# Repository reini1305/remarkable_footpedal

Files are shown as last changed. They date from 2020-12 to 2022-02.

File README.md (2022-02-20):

# Remarkable 2 Foot Pedal

This repository contains schematics, a 3D model and code for a Teensy LC to connect a foot pedal switch to the pogo pins of a reMarkable 2.

## Pictures
Assembled and in action:

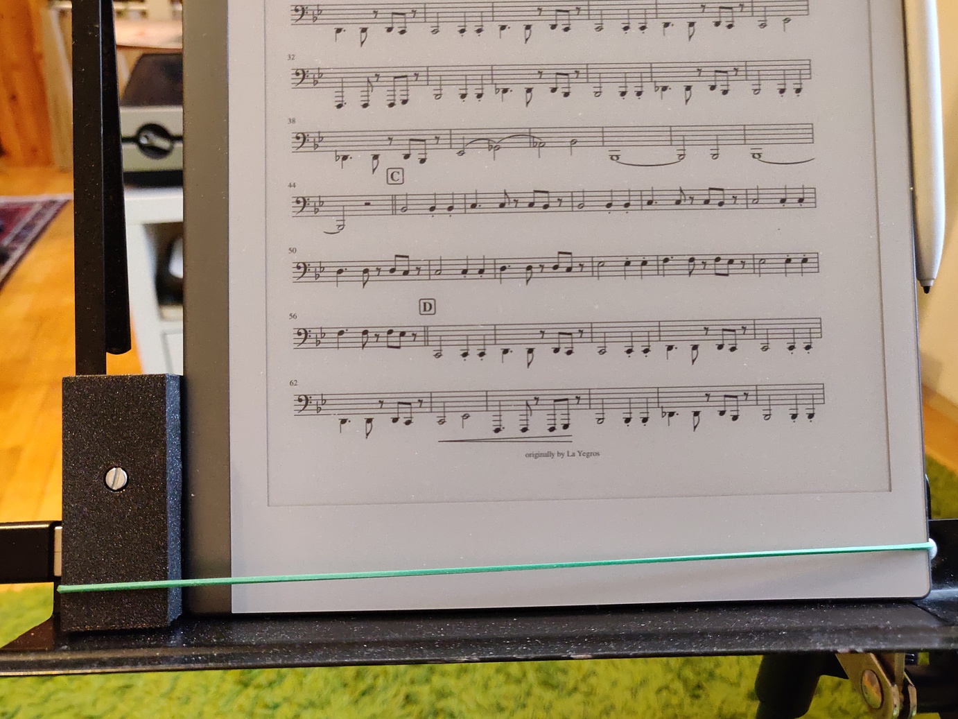
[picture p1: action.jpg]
Action

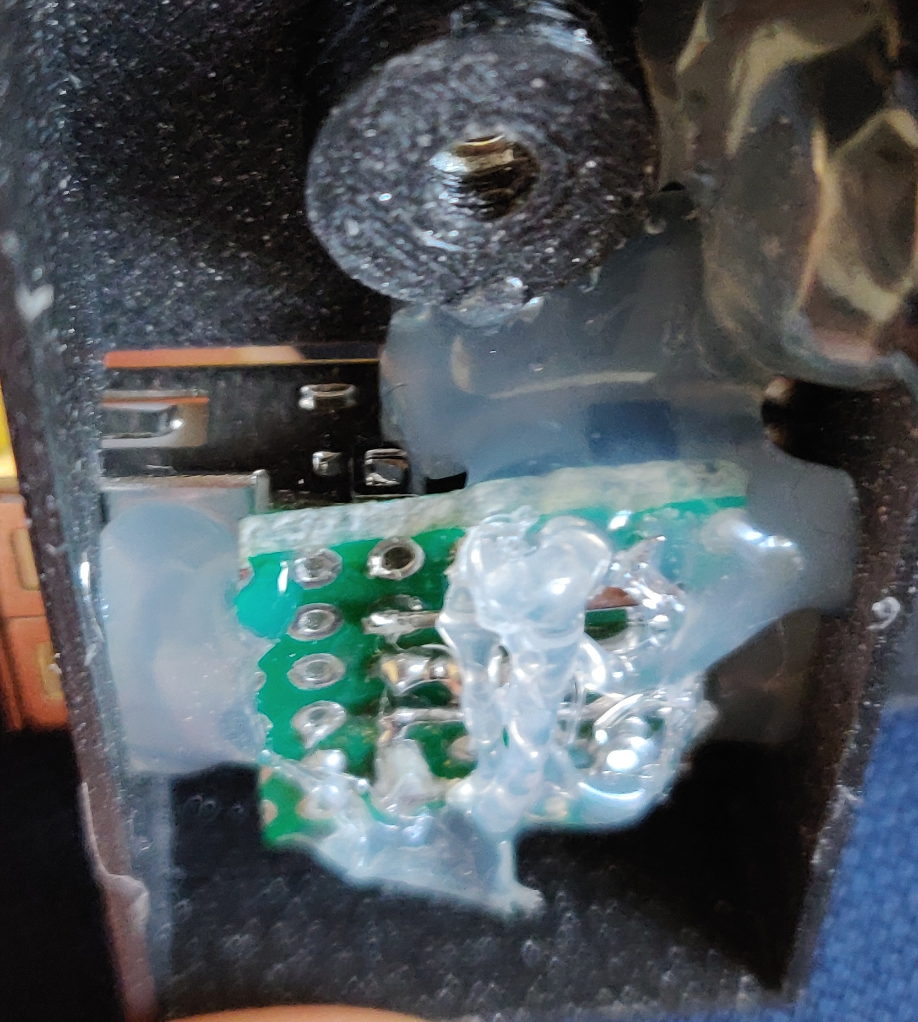
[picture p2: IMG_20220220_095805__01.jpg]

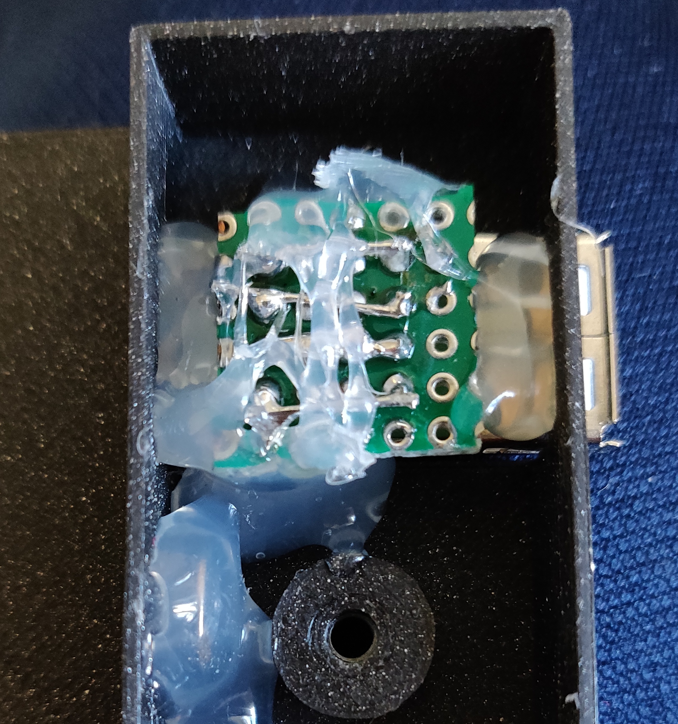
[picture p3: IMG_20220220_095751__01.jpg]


Pogo pin converter:

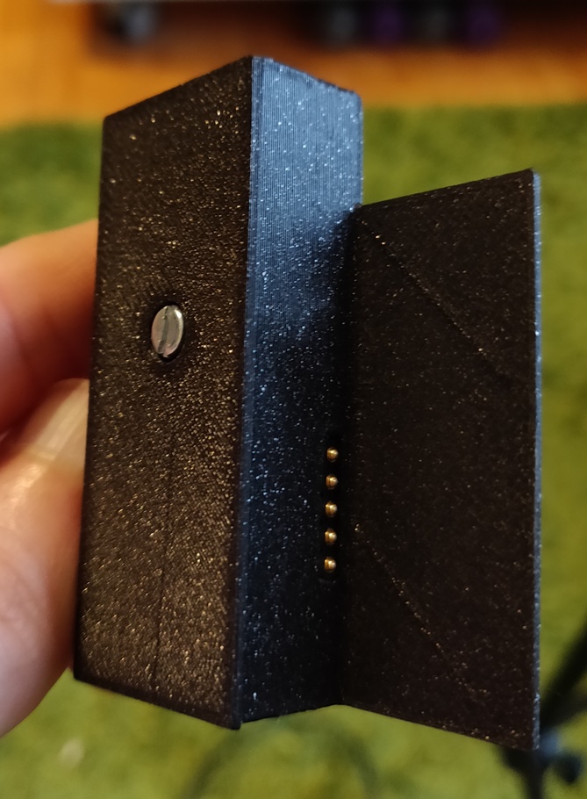
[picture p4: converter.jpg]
Pogo


Foot pedal:

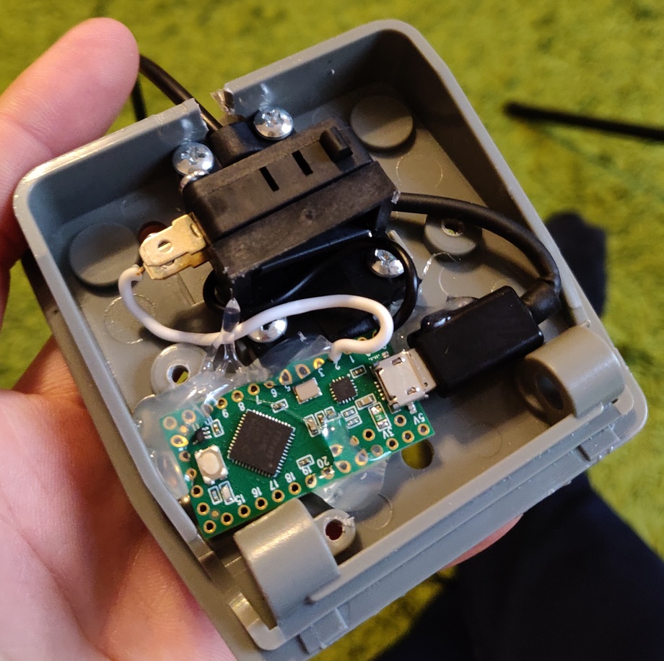
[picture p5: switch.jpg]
Foot pedal


## Necessary Hardware
- Teensy LC (or better) [here](https://www.pjrc.com/teensy/teensyLC.html)
- Foot pedal (e.g. [from Digikey](https://www.digikey.at/product-detail/de/adafruit-industries-llc/423/1528-1137-ND/5353597))
- USB-A connector (e.g. [from Digikey](https://www.digikey.at/product-detail/de/on-shore-technology-inc/USB-A1HSW6/ED2989-ND/2677750))
- Pogo pins (e.g. [from Digikey](https://www.digikey.at/product-detail/de/mill-max-manufacturing-corp/815-22-005-30-001101/ED1232-05-ND/3913218))
- Small neodym magnets to hold the adapter to the RM2

## Schematics
The pinout of the pogo pins is described in the [remarkable wiki](https://remarkablewiki.com/tech/rm2_otg_pogo):
~~~
(left to right, closest to USB-C)  
  
GND, ID, D+, D-, VBUS
~~~
Connecting GND to ID will enable the OTG power supply. If you mount the USB-port upside/down, you can simply connect the pins 1:1 as the USB pinout is:
~~~
(right to left)  
  
GND, D+, D-, VBUS
~~~

For the foot pedal, connect the switch to ground and a pin on the Teensy (the example code uses pin 2).

## Software
The sketch for the Teensy reads the input from pin 2. If it is pressed only once within 300ms, "Arrow Right" will be sent as keypress, it it is pressed twice, "Arrow Left" will be sent. This allows you to move forward and back through the document.

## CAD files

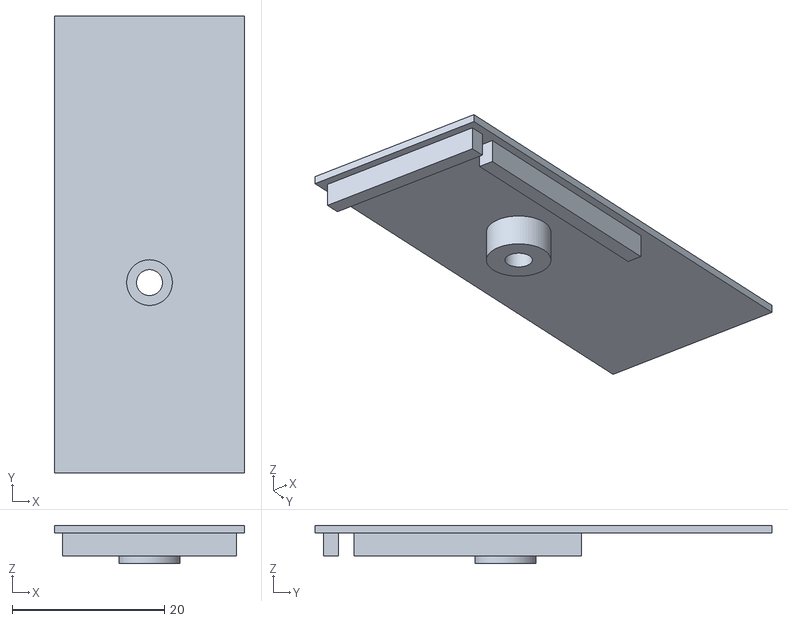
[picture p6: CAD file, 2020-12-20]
top.stl
25.0 x 60.0 x 5.00

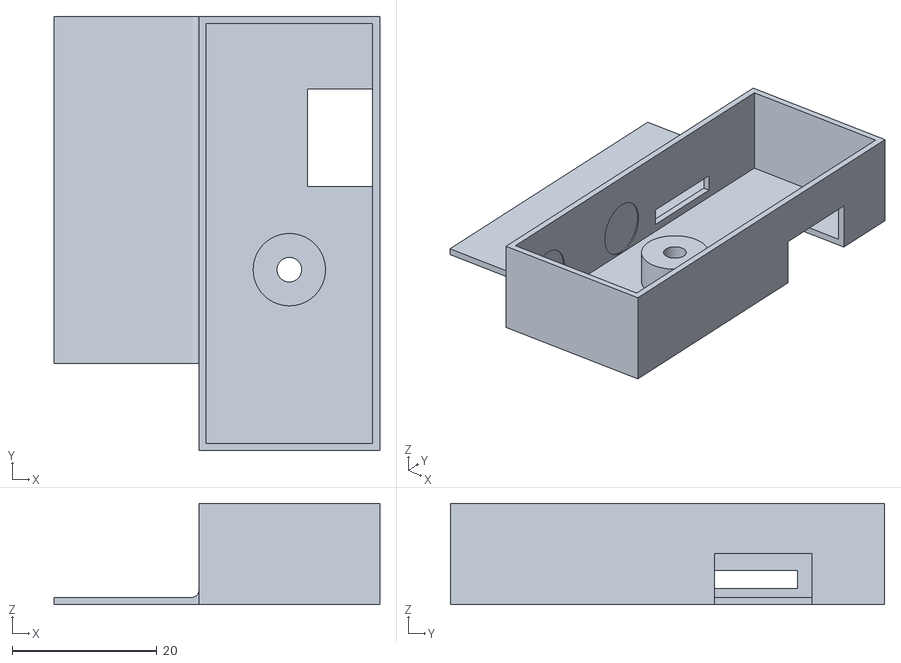
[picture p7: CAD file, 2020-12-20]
bottom.stl
45.0 x 60.0 x 14.0

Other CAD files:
box.FCStd

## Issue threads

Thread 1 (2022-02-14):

Help please!

Cwill95, 2022-02-14:
Hello, I would really like to create this product but am having some trouble!  First, the links in the message for the items needed are going to a web page in another country and in another language, and I’m having a hard time finding them exactly as linked in the US.  Would it be possible to refresh those links to a US based company?  Also not sure  what why’re correct, as the Pogo pins in the link look very different than the ones in the picture (picture shows 5 pins; link shows 4).  I’m also curious if you have some more pictures of the project that you can post with maybe some more detailed instructions?  It would be very much appreciated if possible!!

reini1305, 2022-02-14:
Hi! I've linked to Digikey since it is an international distributor. You might need to change the country in the settings, but you can definitely get everything in the US (with the part numbers). The pogo pins link shows 4 pins, but it is a 5 pin.
I'll open the adapter and try to take some more pictures, but please bear in mind that this is not intended to be a product but an afternoon hack of mine.

Cwill95, 2022-02-14:
Hi Christian, thanks for the quick response!  I think I've gotten the parts I need...  Not sure why your links take me to a german (looking?) page, but none the less, I've ordered the parts!  And I certainly understand what you mean...  I'm not looking to commercialize this either - just an "afternoon hack" for me too!  :-)

So, I'm looking through everything...  Never used Teensy, but I've used arduino before, so mildly familiar with the process here.  It looks like you have some 3d printer files, for printing the box that attaches to the side of the RM2, correct?  And the only thing inside that box is the pogo pins and the USB adapter?  I'm assuming that it will be rather self-intuitive how these pieces fit together inside the box, which is (presumably) two pieces held together by a screw?

The picture of the foot pedal looks like it has a cord coming out of it.  I also assume that somehow the cord to the footpedal is removed, and replaced by a USB cable that attached directly to the Teensy?  So the Teensy and the pogo box are both connected together by a male/male USB cable, is that correct?

Sorry to ask so much of you here, but this is EXACTLY what I've been looking for and I'm really excited to get it going!!

THanks,

Trey

reini1305, 2022-02-20:
Hi! I've attached two more images ofe the inside of the adapter. And yes, the two STL files are for the box to be 3d printed.
You're right that this box allows to plug in any USB device into the remarkable. I've remobed the foot switch cable and instead inserted a USB A to micro USB cable to connect to the Teensy. Instead of a teensy, one could also open up an old USB keyboard and xonnect the switch such that it produces a PgDown keypress to advance the page on the remarkable

Cwill95, 2022-03-14:
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

Hey!!  So I'm finally getting this thing put together and I'm a little confused out the pogo pins...  Did you just solder wires from the usb plug to the pins, and then hot glue everything to hold it in place?  The pic above is what I've got...  ordered everything directly from your links.  Your pic of the 3d printed box looks like it has some type of green board on it but can't tel what it is...  Did I maybe get a different part?

See pic - that's what I have

Cwill95, 2022-03-14:
And also, did you just "Hotwire" the Grn to ID pin?

reini1305, 2022-03-25:
Hi!
Sorry for the late answer. Yes, I've connected GND to ID as in the schematic. The green board is a "peg board" That I've cut to size (just to have something to mount the components to (similar to this https://www.neuhold-elektronik.at/catshop/popup_image.php?pID=7867). I've bent some connectors like those https://www.neuhold-elektronik.at/catshop/popup_image.php?pID=2688 90 degrees and soldered the pogo pins to them.

It should be possible to connect pogo pins and USB connector with wires though and fixing them into position with hot glue.

davidnixon, 2022-06-23:
This is such an awesome project. Thanks for posting! :raising_hand_man: I don't see the magnets in the pics. Can you add a pick of that? Maybe they are here?
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

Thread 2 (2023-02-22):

rm2 experience

cfenell, 2023-02-22:
Hi, a colleague has modified the CAD drawings and built an adapter for me, magnet mounting modified and positions adjusted to fit my rm2.  The magnets help finding the position but are too weak to make contact with the pogo pins, so an additional rubberband or piece of tape will be necessary.

I am  curious- what music viewer do you use in the photos, just the standard reMarkable application or something else?
Best regards, Fredrik

reini1305, 2023-03-07:
Hi! Awesome! I'm using the normal PDF viewer of Remarkable. I usually get sheet music as multi-page PDFs.

cfenell, 2023-04-03:
I'm still struggling to get a reliable connection to the pogo pins, are there any good tricks?
If I press the connector hard with one hand I can make a normal keyboard work in a text terminal for a short while, but the PDF reader does not seem to react.

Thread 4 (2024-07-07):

Using a Seeeduino Xiao SAMD21 instead of Teensy LC

chucktomasi, 2024-07-07:
Thanks for providing this repo. I've been inspired to try to build one myself based on your design. However, instead of the Teensy LC, I've opted to use the Seeeduino Xiao SAMD21 as it's much smaller. The software worked well (after a adding the Keyboard.h header). I can see that it is sending two different codes based on click/double-click.

Here's my issue... when I created the USB-A to pogo interface and tested it, the Xiao only powers on for about a second then goes dark. According to what I could find, it's only drawing 12mA. I believe that's almost half of what the Teensy LC takes. I'm not sure where I've gone wrong. It works fine on the "test bench" when connected to my laptop and Arduino IDE, but it's not powering properly from the RM2. Happy to provide any additional information if needed.

Any thoughts?

Thanks again

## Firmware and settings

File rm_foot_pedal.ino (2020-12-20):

// Detect the falling edge

// Include the Bounce2 library found here :
// https://github.com/thomasfredericks/Bounce-Arduino-Wiring
#include <Bounce2.h>

#define NEXT_KEY KEY_RIGHT_ARROW
#define PREV_KEY KEY_LEFT_ARROW
#define SWITCH_PIN 2

Bounce* bouncer;
unsigned long last_keypress = 0;
unsigned long now = 0;
bool press_key = false;

void setup() {
  // Setup the button with an internal pull-up :
  pinMode(SWITCH_PIN,INPUT_PULLUP);
  bouncer = new Bounce();
  // After setting up the button, setup the Bounce instance :
  bouncer->attach(SWITCH_PIN);
  bouncer->interval(50);
}

void loop() {
  // Update the Bounce instance :
  bouncer->update();
  now = millis();
  if (press_key && now - last_keypress > 300) {
    Keyboard.press(NEXT_KEY);
    delay(10);
    Keyboard.releaseAll();
    press_key = false;
  }
  // Call code if Bounce fell (transition from HIGH to LOW) :
  if ( bouncer->fell() ) {
   // check if we hit the same key within the last 300 ms
   if (now - last_keypress < 300) {
     Keyboard.press(PREV_KEY);
     delay(10);
     Keyboard.releaseAll();
     press_key = false;
   } else {
     press_key = true;
   }
   last_keypress = now;
  }
}
